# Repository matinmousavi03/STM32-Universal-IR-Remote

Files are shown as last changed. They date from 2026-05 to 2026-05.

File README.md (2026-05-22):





# STM32 Universal IR Recorder & Replayer

An STM32-based embedded system capable of **capturing, storing, and replaying** raw infrared remote control signals with protocol‑independent timing analysis. Unlike protocol‑specific decoders, this project stores raw timing, allowing support for virtually any consumer IR protocol (NEC, RC‑5, Sony SIRC, AC units, etc.).

> **Note:** Schematic, PCB layout, and detailed Persian documentation will be added later in the `hardware/` and `docs/` folders.

<!-- Images coming soon  
![PCB](Images/pcb.jpg)  
*Custom PCB design*  

![Prototype](Images/board.jpg)  
*Hardware prototype on Blue Pill + keypad*  

![IR Waveform](Images/waveform.png)  
*Example captured NEC signal (38 kHz carrier)*  
-->

## Features

- **Protocol‑agnostic** – Works with any consumer IR remote (NEC, RC‑5, Sony SIRC, AC units, etc.)  
  Carrier frequency range 30–56 kHz, raw timing stored with µs precision.
- **Store up to 10 channels** in internal Flash (2 KB per channel, persistent across resets).
- **Replay** stored signals with accurate carrier frequency and timing (PWM + DWT delays).
- **User interface** – 4×4 matrix keypad + status LED.
- **Power management** – Auto standby after 30 seconds idle, wake on keypress.
- **Debug friendly** – UART1 (115200 baud) for real‑time logging.

## Software Architecture

The firmware is built around a **central event‑driven state machine**:

IR_IDLE → IR_RECEIVING → IR_READY → (save/cancel/transmit/delete) → IR_IDLE
(IR_SELECTING for channel choice)

**Timer usage:**

| Timer | Role |
|---|---|
| TIM2  | Input capture of IR edge timing (1 MHz) |
| TIM3  | PWM carrier generation for transmission |
| TIM4  | End‑of‑frame detection (250 ms silence) |
| TIM1  | User decision timeout (5 s) and idle standby |

**Key modules in code:**

- `ProcessDiffBuffer()` – Converts raw `diff` array to `IR_RawData` segments.
- `SaveToFlash()`, `LoadFromFlash()` – Persistent storage in custom Flash sections.
- `IR_Transmit()` – Replays signal using `delay_us()` (DWT cycle counter).
- `ScanKeyboard()` – Polls 4×4 matrix with IRQ disable to avoid false triggers.

## Flash Memory Layout

Custom linker script reserves dedicated Flash pages for persistent data:

| Section | Size  | Purpose |
|---|---|---|
| `.occupied` | 1 KB  | Byte map of channel occupancy (0 = empty, 1 = used) |
| `.user_data`  | 20 KB | Raw IR channel data (10 channels × 2 KB) |

*Both sections are `NOLOAD` to avoid initialisation – they are erased (0xFF) after programming. The firmware detects this and initialises to empty.*

## Hardware Connections

| Component | Pin(s) | Note |
|---|---|---|
| IR receiver input  | **PA15 (TIM2 CH1)** | Falling edge, pull‑up, **partial remap** |
| Wake‑up pin | **PA0 (WKUP)** | Pull‑down, used to exit STANDBY |
| IR transmitter out | PA6 (TIM3 CH1) | PWM, driven by BC107 transistor |
| Keypad rows | PB6, PB7, PB8, PB9 | Outputs, driven LOW during scan |
| Keypad columns | PB3, PB4, PB5, **PB15** | Inputs with pull‑up, EXTI |
| Status LED | PC13 | Active LOW |
| Debug UART | PA9 (TX), PA10 (RX) | 115200 baud |

## Schematic

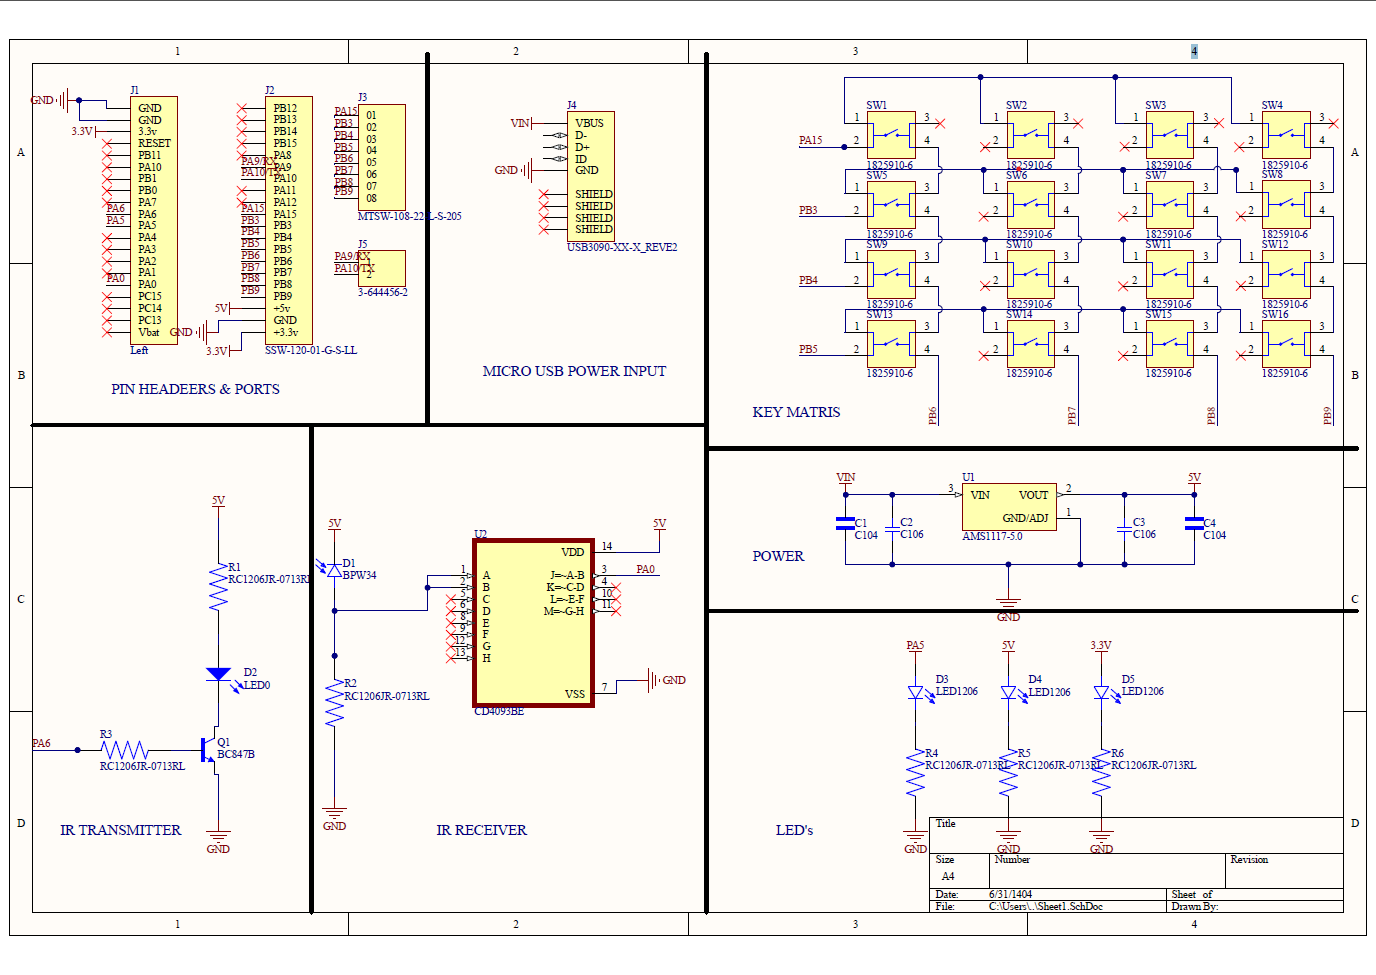
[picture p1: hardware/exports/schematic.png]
Schematic


*Complete schematic of IR receiver, transmitter, keypad, and STM32 connections*

## Hardware Prototype

**Top layer:**  
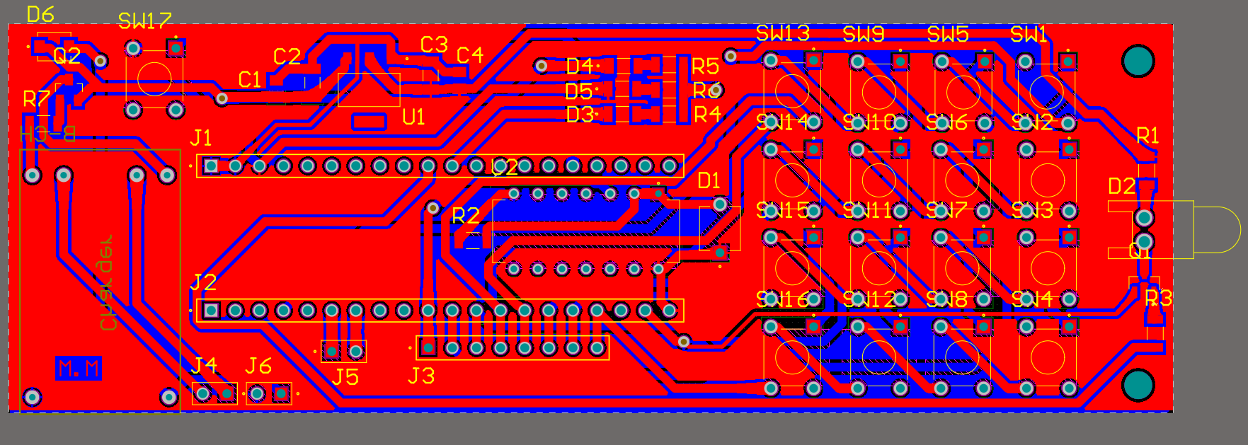
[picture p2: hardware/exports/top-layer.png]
Top layer


<br>

**Bottom layer:**  
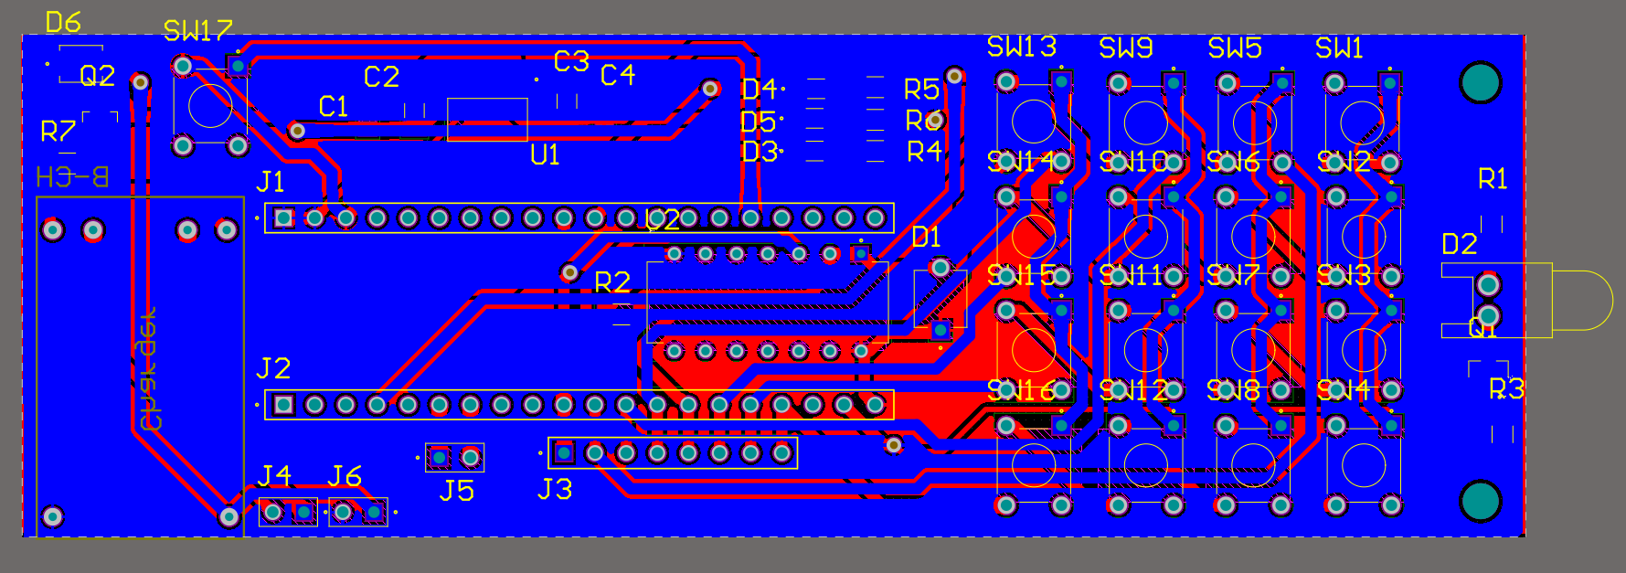
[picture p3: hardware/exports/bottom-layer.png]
Bottom layer


<br>

**3D PCB view:**  
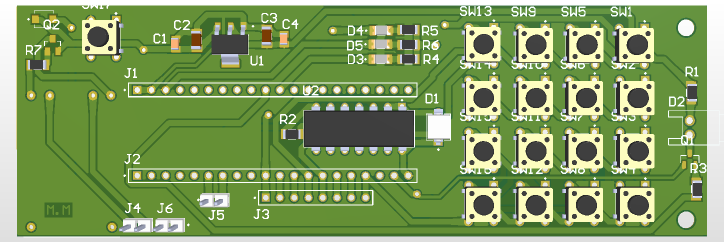
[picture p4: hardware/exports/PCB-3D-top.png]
3D PCB view


## PCB Errata & Design Tips

The following hardware issues were identified in the current PCB revision. Workarounds and fixes for future revisions are provided below.

### 1. IR LED Driver Transistor (Q1) – Footprint Swap
- **Issue:** Base and emitter pins were swapped during routing. The base was connected to GND and the emitter to the PWM signal (TIM3_CH1), making the transistor inoperative.
- **Workaround:** Physically rotate the transistor 180° before soldering (reverse orientation). This corrects the pinout.
- **Fix for next revision:** Correct the footprint so that base connects to the MCU output and emitter goes to GND.

### 2. UART Test Points (J5) & Keypad Connector (J3) Placement
- **Issue:** 
  - **J5 (UART – PA9, PA10):** Positioned too high on the board, difficult to access when mounted in an enclosure.
  - **J3 (Keypad connector):** Unnecessary and placed poorly.
- **Workaround:** 
  - For J5: Use right‑angle (90°) pin headers or manually extend cables.
  - For J3: Do not populate; directly solder keypad wires to the PCB or remove the connector footprint in the next revision.
- **Fix for next revision:** 
  - Move J5 lower on the board or use right‑angle headers.
  - **Remove J3 entirely** – the keypad can be connected via separate wires or a different connector.

### 3. Polygon Pour Clearance
- **Issue:** Large copper pours with insufficient clearance to pads and traces make hand soldering difficult. Heat dissipates quickly, requiring higher soldering temperatures and increasing the risk of bridging.
- **Recommendation:** Increase clearance to at least 0.3 mm (12 mil) or use thermal relief spokes (thermals) on pads connected to pours.
- **Fix for next revision:** Adjust polygon clearance settings and verify thermal reliefs in the PCB layout.

### Hardware Notes

- **TIM2 input capture is remapped to PA15** (`__HAL_AFIO_REMAP_TIM2_PARTIAL_1()`) because PA0 is reserved for the STANDBY wake‑up pin (WKUP). The IR receiver is physically connected to PA15.
- PA0 is configured as a pull‑down input and used only for waking up from STANDBY (EXTI line 0).
- The keypad uses PB15 as its fourth column – **no conflict** with the IR input. All column pins (PB3, PB4, PB5, PB15) have internal pull‑ups and trigger EXTI interrupts for scanning.
- 

## Building the Project

1. Open STM32CubeIDE.
2. **Import the existing project** from the repository root (File → Import → Existing Projects).
3. If you prefer to start fresh, create a new project for STM32F103C8T6 and then replace the generated files:
   - Copy `main.c`, `stm32f1xx_it.c`, `stm32f1xx_hal_msp.c` into `Core/Src/`
   - Copy `stm32f1xx_hal_conf.h` into `Core/Inc/`
   - **Replace the linker script** with `STM32F103C8TX_FLASH.ld` (provided in the root).
4. Compile and flash via ST‑LINK.

> **Important:** The custom linker script defines the two Flash sections (`.user_data` and `.occupied`). Without it, the channel storage will overlap with code and cause hard faults.

## Usage Guide

### 1. Capture a Signal
- Point an existing remote at the IR receiver.
- After capture, the LED lights solid.
- Within 5 seconds:
  - Press `A` to save to the **first free channel**.
  - Or enter a **channel number** (1‑10) then `A` to overwrite/choose a specific channel.
  - Press `B` to discard the signal.

### 2. Transmit a Saved Signal
- Enter a channel number (1‑10), press `#`, then press `C`.

### 3. Delete a Channel
- Enter channel number, press `#`, then press `D`.

### 4. Standby Mode
- After 30 seconds of inactivity, the system enters **STANDBY** (low power). Press any key to wake up.

## Known Issues & Workarounds

- **Occupied page initialisation** – Because `.occupied` is `NOLOAD`, the first read returns `0xFF`. `LoadOccupiedFromFlash()` detects this and resets the map to all empty. If you need a pre‑populated map, remove `NOLOAD` from the linker script and provide initial data.
- **Debouncing** – Only simple software debounce (40 ms in EXTI callback). Very fast double‑presses may be missed, but fine for typical user input.
- **Flash write during capture** – Erasing/programming disables TIM2 and TIM4 interrupts for a few milliseconds. In noisy environments, a capture edge could be lost. A future improvement would be double‑buffering or a background Flash task.
- **EXTI interrupt priority** – Must be **lower than TIM2 capture priority** to avoid race conditions. In this project, EXTI priority is set to 2, TIM2 priority to 1 (configurable via `HAL_NVIC_SetPriority`).

## References

- [STM32F103C8T6 Datasheet](https://www.st.com/resource/en/datasheet/stm32f103c8.pdf) – STMicroelectronics
- [NEC Infrared Transmission Protocol](https://www.renesas.com/us/en/document/apn/nec-infrared-transmission-protocol) – Renesas
- [CD4093B Datasheet (Quad NAND Schmitt Trigger)](https://www.ti.com/lit/ds/symlink/cd4093b.pdf) – Texas Instruments
- [BPW34 Photodiode Datasheet](https://www.vishay.com/docs/81521/bpw34.pdf) – Vishay
- [STM32 HAL Driver User Manual](https://www.st.com/resource/en/user_manual/dm00105879-description-of-stm32f1-hal-and-lowlayer-drivers-stmicroelectronics.pdf)

## License

MIT License – see [LICENSE](LICENSE) file for details.

---

## Suggested GitHub Topics

`stm32` `stm32f103` `embedded` `embedded-c` `stm32-hal` `infrared` `ir-remote` `electronics` `microcontroller` `ir-decoder` `universal-remote`

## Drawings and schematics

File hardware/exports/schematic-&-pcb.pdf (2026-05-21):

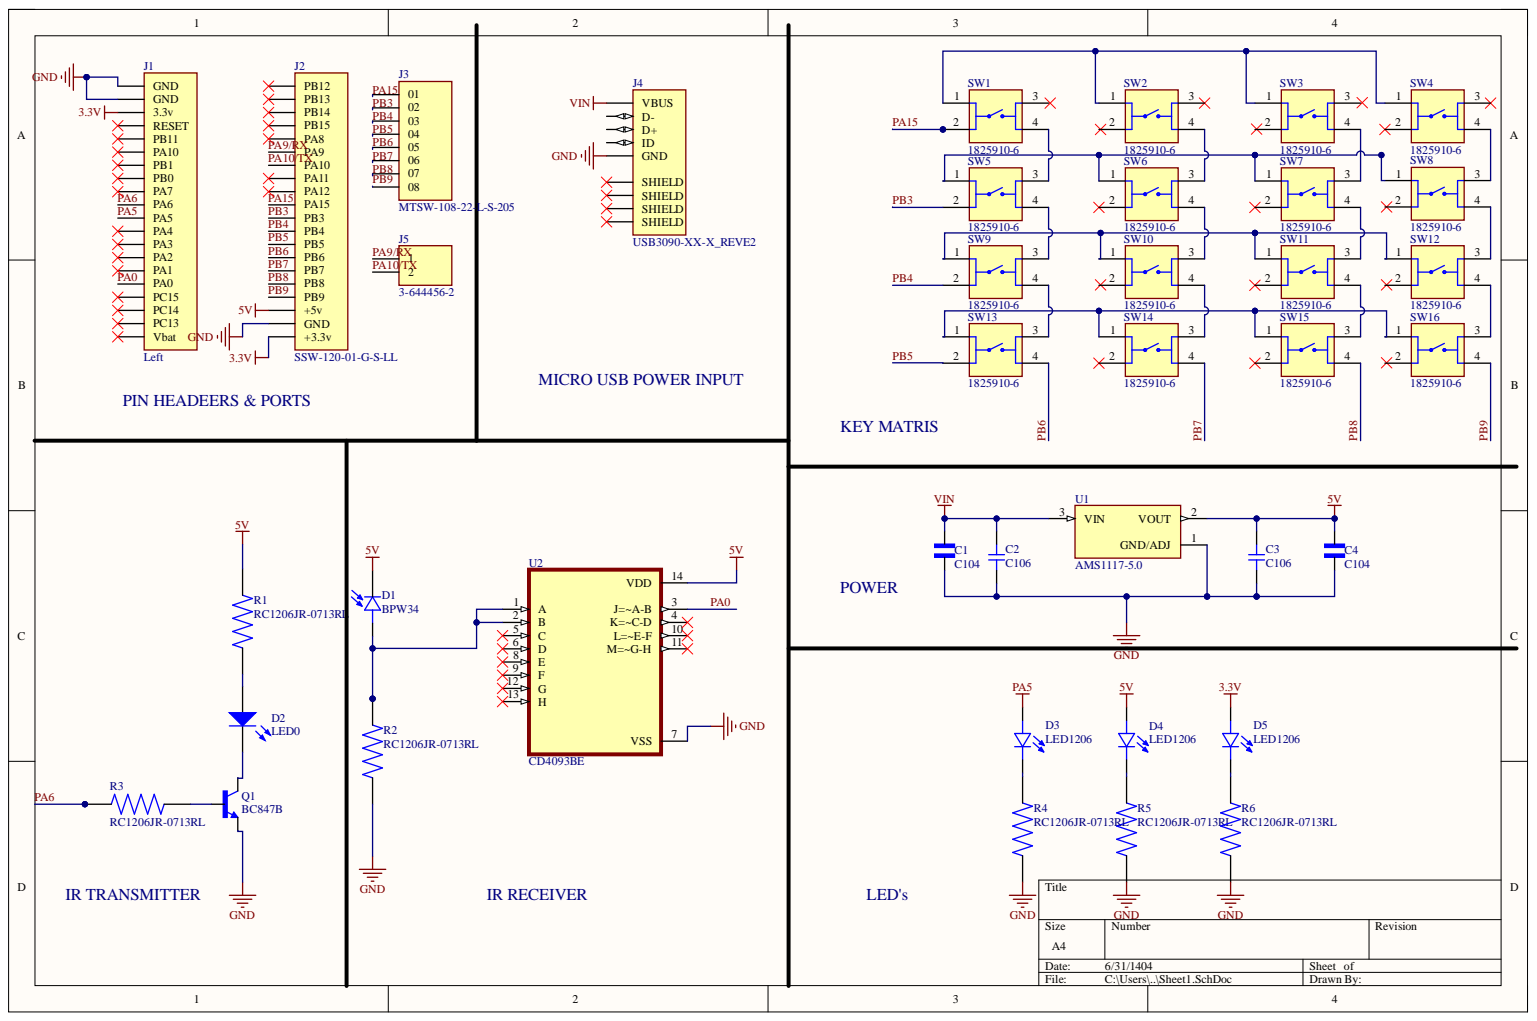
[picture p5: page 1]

5 | 1 0

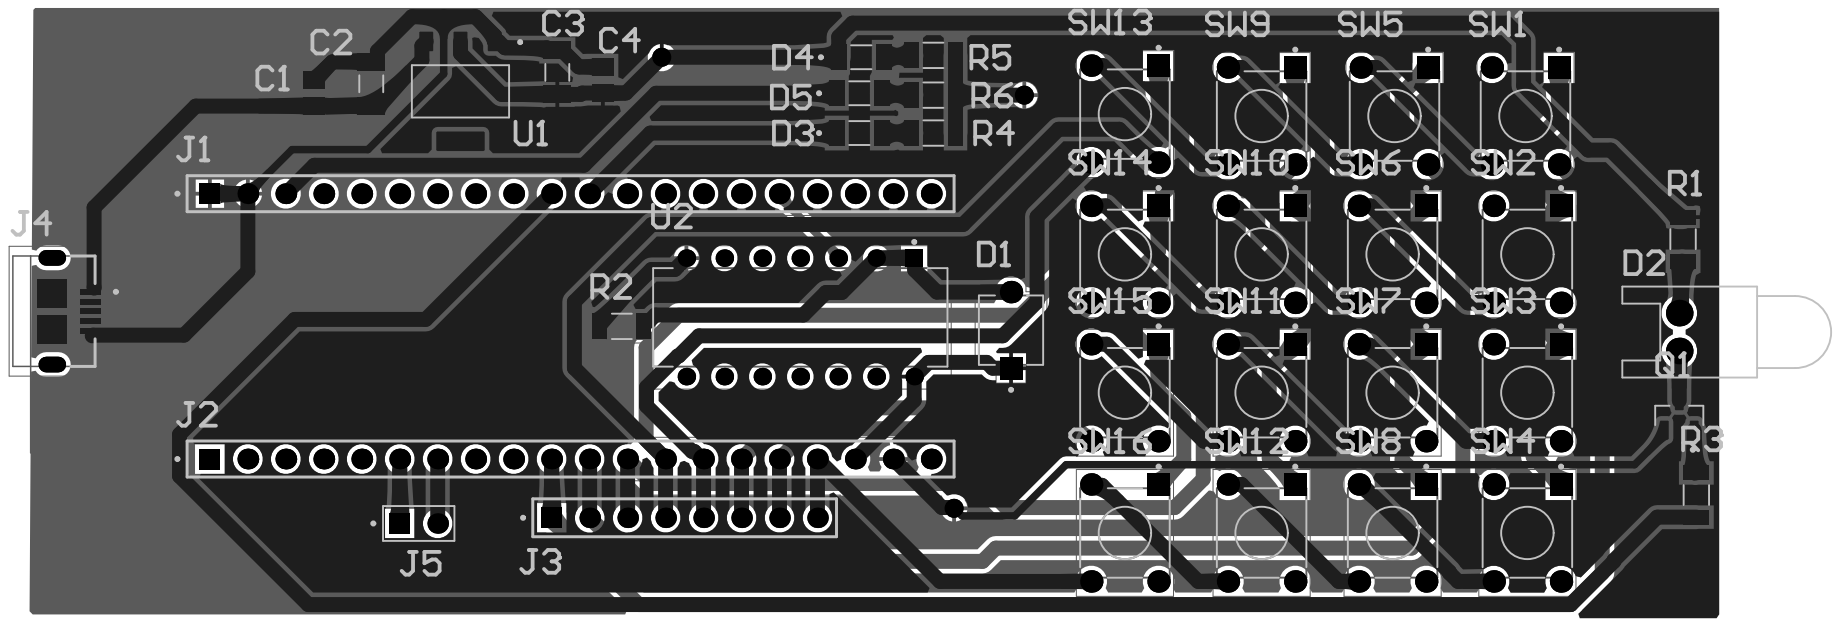
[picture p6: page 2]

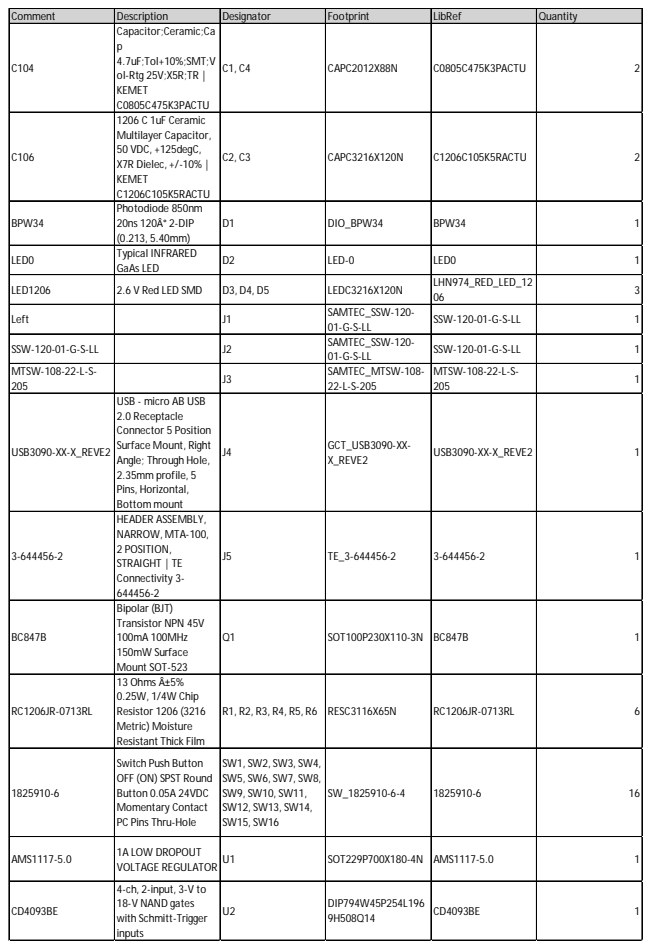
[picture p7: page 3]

Comment | Description | Designator | Footprint | LibRef | Quantity
C104 | Capacitor;Ceramic;Ca p 4.7uF;Tol+10%;SMT;V ol-Rtg 25V;X5R;TR | KEMET C0805C475K3PACTU | C1, C4 | CAPC2012X88N | C0805C475K3PACTU | 2

C106 | 1206 C 1uF Ceramic Multilayer Capacitor, 50 VDC, +125degC, X7R Dielec, +/-10% | KEMET C1206C105K5RACTU | C2, C3 | CAPC3216X120N | C1206C105K5RACTU | 2

BPW34 | Photodiode 850nm 20ns 120Â° 2-DIP (0.213, 5.40mm) | D1 | DIO_BPW34 | BPW34 | 1

LED0 | Typical INFRARED GaAs LED | D2 | LED-0 | LED0 | 1

LED1206 | 2.6 V Red LED SMD | D3, D4, D5 | LEDC3216X120N | LHN974_RED_LED_12 06 | 3

Left | | J1 | SAMTEC_SSW-120-01-G-S-LL | SSW-120-01-G-S-LL | 1

SSW-120-01-G-S-LL | | J2 | SAMTEC_SSW-120-01-G-S-LL | SSW-120-01-G-S-LL | 1

MTSW-108-22-L-S-205 | | J3 | SAMTEC_MTSW-108-22-L-S-205 | MTSW-108-22-L-S-205 | 1

USB3090-XX-X_REVE2 | USB - micro AB USB 2.0 Receptacle Connector 5 Position Surface Mount, Right Angle; Through Hole, 2.35mm profile, 5 Pins, Horizontal, Bottom mount | J4 | GCT_USB3090-XX-X_REVE2 | USB3090-XX-X_REVE2 | 1

3-644456-2 | HEADER ASSEMBLY, NARROW, MTA-100, 2 POSITION, STRAIGHT | TE Connectivity 3-644456-2 | J5 | TE_3-644456-2 | 3-644456-2 | 1

BC847B | Bipolar (BJT) Transistor NPN 45V 100mA 100MHz 150mW Surface Mount SOT-523 | Q1 | SOT100P230X110-3N | BC847B | 1

RC1206JR-0713RL | 13 Ohms Â±5% 0.25W, 1/4W Chip Resistor 1206 (3216 Metric) Moisture Resistant Thick Film | R1, R2, R3, R4, R5, R6 | RESC3116X65N | RC1206JR-0713RL | 6

1825910-6 | Switch Push Button OFF (ON) SPST Round Button 0.05A 24VDC Momentary Contact PC Pins Thru-Hole | SW1, SW2, SW3, SW4, SW5, SW6, SW7, SW8, SW9, SW10, SW11, SW12, SW13, SW14, SW15, SW16 | SW_1825910-6-4 | 1825910-6 | 16

AMS1117-5.0 | 1A LOW DROPOUT VOLTAGE REGULATOR | U1 | SOT229P700X180-4N | AMS1117-5.0 | 1

CD4093BE | 4-ch, 2-input, 3-V to 18-V NAND gates with Schmitt-Trigger inputs | U2 | DIP794W45P254L196 9H508Q14 | CD4093BE | 1

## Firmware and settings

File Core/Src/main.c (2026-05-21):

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
/* Includes ------------------------------------------------------------------*/
#include "main.h"

/* USER CODE BEGIN Includes */
#include <string.h>
#include <stdio.h>

#include "stm32f1xx_hal.h"
#include "stm32f1xx_hal_rcc.h"

#include <stdlib.h>  // for atoi


/* Reserve Flash space for channel storage (10 channels * 2KB each) */
__attribute__((section(".user_data"))) const uint8_t flash_channels[10 * 2048];
/* Reserve one Flash page (1KB) for occupied channel map */
__attribute__((section(".occupied"))) const uint8_t occupied_page[1024];

/* USER CODE END Includes */

/* USER CODE BEGIN PD */

/* IR signal processing thresholds */
#define BURST_GAP_US    70        /* Max duration to consider as part of a burst (carrier) */
#define MAX_SEGMENTS    256       /* Max number of burst/idle segments per signal */
#define MAX_DIFFS       3000      /* Reduced from 4096 to save RAM (8KB) */
#define TIMER_FREQ_HZ   1000000   /* TIM2 runs at 1 MHz → 1 µs per tick */
#define END_GAP_US      500000    /* 500 ms silence to force end of capture (fallback) */

/* Signal validation thresholds */
#define MIN_CARRIER_COUNT 5          /* Minimum pulses to calculate carrier frequency */
#define MIN_TOTAL_DURATION_US 50000  /* Minimum total signal duration (50 ms) */
#define MAX_TOTAL_DURATION_US 200000 /* Maximum total signal duration (200 ms) */
#define MIN_BURST_DURATION_US 100    /* Minimum burst length to reject noise */
#define MIN_IDLE_DURATION_US  50     /* Minimum idle length to reject short gaps */
#define CARRIER_FREQ_MIN_HZ   30000  /* Min carrier frequency (30 kHz) */
#define CARRIER_FREQ_MAX_HZ   50000  /* Max carrier frequency (50 kHz) */
#define MIN_DIFFS_FOR_PROCESS 10     /* Ignore signals with fewer diffs (noise) */

/* Flash memory layout */
#define FLASH_END_ADDRESS           0x08010000  /* End of 64KB Flash (base + 64KB) */
#define MY_FLASH_PAGE_SIZE          1024U       /* Page size (renamed to avoid conflict(redefining FLASH_PAGE_SIZE error)) */
#define FLASH_OCCUPIED_START ((uint32_t)occupied_page)
#define FLASH_CHANNELS_START ((uint32_t)flash_channels)
#define CHANNEL_SIZE_IN_FLASH       (MY_FLASH_PAGE_SIZE * PAGES_PER_CHANNEL) // حالا با MY_ استفاده می‌شه

/* IR channel configuration */
#define MAX_CHANNELS    10
#define PAGES_PER_CHANNEL    2   /* 2 pages = 2KB per channel */

#define IDLE_THRESHOLD 6  /* 6 * 5s = 30s idle timeout */

/* USER CODE END PD */

TIM_HandleTypeDef htim1;
TIM_HandleTypeDef htim2;
TIM_HandleTypeDef htim3;
TIM_HandleTypeDef htim4;

UART_HandleTypeDef huart1;

/* USER CODE BEGIN PV */

/* EXTI flag for keypad interrupt */
volatile uint8_t exti_flag = 0;

/* Raw diff buffer (timing between edges) */
volatile uint32_t diffBuffer[MAX_DIFFS];
volatile uint32_t diffIndex = 0;

/* Capture state flags */
volatile uint8_t captureActive = 1;       /* Set to 0 to stop capture */
volatile uint8_t signalDetected = 0;      /* First valid edge detected */

/* Structure to hold processed IR signal data */
typedef struct {
    uint32_t carrierFreq;
    uint16_t segmentCount;
    uint8_t  type[MAX_SEGMENTS];      /* 0 = Idle, 1 = Burst */
    uint32_t duration[MAX_SEGMENTS];  /* microseconds */
} IR_RawData;

/* Current captured signal (volatile because used in ISR) */
volatile IR_RawData irData;

volatile uint32_t lastCapture = 0;
volatile uint8_t signalReady = 0;     /* Set when capture finished or overflow */
volatile uint8_t overflowError = 0;   /* Diff buffer overflow flag */

//phase 3
/* Temporary buffer for Flash read/write (one channel) */
IR_RawData tempChannelData;

/* State machine states */
typedef enum {
    IR_IDLE,         /* Waiting for signal or user input */
    IR_RECEIVING,    /* Capture in progress */
    IR_READY,        /* Signal ready, waiting for save/cancel */
    IR_TRANSMITTING, /* Replaying stored signal */
	IR_SELECTING     /* User selected channel, waiting for C (send) or D (delete) */
} IR_State;

volatile IR_State currentState = IR_IDLE;

/* Channel occupancy map (0 = free, 1 = occupied) */
uint8_t channelOccupied[MAX_CHANNELS] = {0};

/* Keyboard input buffer (max 2 digits + null terminator) */
uint8_t selectedChannel = 0;
uint8_t keyboardBuffer[3] = {0};
uint8_t keyboardIndex = 0;

/* User timeout duration (not used dynamically yet, kept for future) */
//uint32_t timeoutDuration = 0;

/* Button flags for polling in main loop (not used in current implementation) */
//uint8_t savePressed = 0, cancelPressed = 0, sendPressed = 0, deletePressed = 0;

/* Word-aligned buffer for Flash programming (BSS) */
static uint32_t saveBuf[(sizeof(IR_RawData) + 3) / 4];

//phase 4
/* Idle timeout handling for standby mode */
volatile uint32_t lastActivityTime = 0;
const uint32_t IDLE_TIMEOUT_MS = 30000;

/* USER CODE END PV */

void SystemClock_Config(void);
static void MX_GPIO_Init(void);
static void MX_TIM2_Init(void);
static void MX_USART1_UART_Init(void);
static void MX_TIM4_Init(void);
static void MX_TIM3_Init(void);
static void MX_TIM1_Init(void);
/* USER CODE BEGIN PFP */

//phase 3
/* Channel management */
static uint8_t FindNextFreeChannel(void);
static void SaveChannel(uint8_t ch);
static void DeleteChannel(uint8_t ch);

/* Flash operations */
HAL_StatusTypeDef SaveToFlash(uint8_t channelIndex, IR_RawData* data);
void LoadFromFlash(uint8_t channelIndex, IR_RawData* destination);
static void LoadOccupiedFromFlash(void);  /* Load channel occupancy from Flash at startup */
static HAL_StatusTypeDef SaveOccupiedToFlash(void);

/* User interface */
static uint8_t ScanKeyboard(void);  /* Scan 4x4 keypad, return ASCII key or 0 */
static void ProcessKeyboardInput(uint8_t key);
static void LED_Pattern(uint8_t type);  /* type: 1=save, 2=cancel, 3=send, 4=delete, 5=error */

/* Debug helpers */
static void DumpOccupiedFlashRaw(void);

/* User timeout management (TIM1) */
static inline void StartUserTimeout(void);
static inline void StopUserTimeout(void);

/* USER CODE END PFP */

/* USER CODE BEGIN 0 */

/**
 * @brief Initializes and starts IR capture mode.
 *        Resets buffers, flags, and starts TIM2 input capture interrupt.
 */
void IR_CaptureStart(void)
{
    memset((void*)diffBuffer, 0, sizeof(diffBuffer));
    diffIndex = 0;
    signalReady = 0;
    overflowError = 0;
    lastCapture = 0;
    captureActive = 1;
    signalDetected = 0;

    HAL_TIM_IC_Start_IT(&htim2, TIM_CHANNEL_1);
    currentState = IR_IDLE;
	printf("Entered receiving state.\r\n");

}

/**
 * @brief TIM2 input capture interrupt callback.
 *        Measures time between falling edges, stores diffs in buffer,
 *        and starts TIM4 timeout on first valid edge.
 */
void HAL_TIM_IC_CaptureCallback(TIM_HandleTypeDef *htim)
{
    if (htim->Instance != TIM2 || !captureActive) return;

    uint32_t now = HAL_TIM_ReadCapturedValue(htim, TIM_CHANNEL_1);
    uint32_t diff = (now >= lastCapture) ? (now - lastCapture) : (0xFFFF - lastCapture + now + 1);

    /* Skip first capture (no valid diff) */
    if (lastCapture == 0) {
            lastCapture = now;
            return;
    }

    if (diffIndex < MAX_DIFFS) {
        diffBuffer[diffIndex++] = diff;
    } else {
    	/* Buffer overflow: stop capture and signal ready for processing */
        overflowError = 1;
        captureActive = 0;
        HAL_TIM_IC_Stop_IT(&htim2, TIM_CHANNEL_1);
        HAL_TIM_Base_Stop_IT(&htim4);
        signalReady = 1;
    }

    lastCapture = now;

    /* Start TIM4 timeout only on the first valid edge */
    if (!signalDetected) {
        signalDetected = 1;
        __HAL_TIM_SET_COUNTER(&htim4, 0);
        HAL_TIM_Base_Start_IT(&htim4);
        currentState = IR_RECEIVING;

    }
}

/**
 * @brief TIM period elapsed callback (used by TIM4 and TIM1).
 *        TIM4: end-of-frame detection, stops capture.
 *        TIM1: user decision timeout (5s), discards signal or selection.
 */
__attribute__((used)) void HAL_TIM_PeriodElapsedCallback(TIM_HandleTypeDef *htim) {
    if (htim->Instance == TIM4) {
    	/* End of capture timeout (no signal edge for 250ms) */
        if (captureActive) {
            captureActive = 0;
            HAL_TIM_IC_Stop_IT(&htim2, TIM_CHANNEL_1);
            HAL_TIM_Base_Stop_IT(&htim4);
            signalReady = 1;  /* Signal ready for processing */
        }
        return;
    }

    if (htim->Instance == TIM1) {

    	/* 5-second user timeout window (ready or channel selection) */
    	StopUserTimeout();

        if (currentState == IR_READY) {
        	lastActivityTime = HAL_GetTick();
        	printf("Timeout in ready state: Signal discarded.\r\n");
            //LED_Pattern(2);
            HAL_GPIO_WritePin(GPIOC, GPIO_PIN_13, GPIO_PIN_SET); /* Turn LED off */
            currentState = IR_IDLE;
            selectedChannel = 0;
            keyboardIndex = 0;
            memset(keyboardBuffer, 0, sizeof(keyboardBuffer));
            //printf("Timeout in ready state: Signal discarded.\r\n");
            IR_CaptureStart(); /* Restart capture */
        }
        else if (currentState == IR_SELECTING && selectedChannel > 0) {
        	lastActivityTime = HAL_GetTick();
            printf("Timeout in channel selection: Channel %d discarded.\r\n", selectedChannel);
            selectedChannel = 0;
            HAL_GPIO_WritePin(GPIOC, GPIO_PIN_13, GPIO_PIN_SET); /* Turn LED off */
            currentState = IR_IDLE;
            IR_CaptureStart();
        }

        return;
    }
}


/**
 * @brief Retarget printf to UART1.
 * @param file unused
 * @param ptr data buffer
 * @param len length
 * @return number of bytes written
 */
int _write(int file, char *ptr, int len)
{
    HAL_UART_Transmit(&huart1, (uint8_t*)ptr, len, HAL_MAX_DELAY);
    return len;
}

/**
 * @brief Show visual feedback on LED (PC13, active low).
 * @param type 1=Save, 2=Cancel, 3=Send, 4=Delete, 5=Error
 */
void LED_Pattern(uint8_t type) {
    switch (type) {
        case 1:  /* Save: 3 quick blinks */
            for (int i = 0; i < 3; i++) {
                HAL_GPIO_WritePin(GPIOC, GPIO_PIN_13, GPIO_PIN_RESET);
                HAL_Delay(150);
                HAL_GPIO_WritePin(GPIOC, GPIO_PIN_13, GPIO_PIN_SET);
                HAL_Delay(150);
            }
            break;
        case 2:  /* Save: 3 quick blinks */
            HAL_GPIO_WritePin(GPIOC, GPIO_PIN_13, GPIO_PIN_RESET);
            HAL_Delay(500);
            HAL_GPIO_WritePin(GPIOC, GPIO_PIN_13, GPIO_PIN_SET);
            HAL_Delay(200);
            break;
        case 3:  /* Send: 2 medium blinks */
            for (int i = 0; i < 2; i++) {
                HAL_GPIO_WritePin(GPIOC, GPIO_PIN_13, GPIO_PIN_RESET);
                HAL_Delay(300);
                HAL_GPIO_WritePin(GPIOC, GPIO_PIN_13, GPIO_PIN_SET);
                HAL_Delay(300);
            }
            break;
        case 4:  /* Delete: 4 fast blinks */
            for (int i = 0; i < 4; i++) {
                HAL_GPIO_WritePin(GPIOC, GPIO_PIN_13, GPIO_PIN_RESET);
                HAL_Delay(100);
                HAL_GPIO_WritePin(GPIOC, GPIO_PIN_13, GPIO_PIN_SET);
                HAL_Delay(100);
            }
            break;
        case 5:  /* Error: 5 very fast blinks */
			for (int i = 0; i < 5; i++) {
				HAL_GPIO_WritePin(GPIOC, GPIO_PIN_13, GPIO_PIN_RESET);
				HAL_Delay(50);
				HAL_GPIO_WritePin(GPIOC, GPIO_PIN_13, GPIO_PIN_SET);
				HAL_Delay(50);
			}
			break;
        default:
            break;
    }
}

/**
 * @brief Dynamically set TIM3 PWM frequency for IR carrier.
 * @param carrierHz Desired carrier frequency (30-56 kHz). Out-of-range defaults to 38 kHz.
 */
void TIM3_SetCarrierFreq(uint32_t carrierHz)
{
    if (carrierHz < 30000 || carrierHz > 50000) {
        carrierHz = 38000; /* Default to 38 kHz */
    }

    /* Calculate timer clock (APB1) */
    uint32_t pclk1 = HAL_RCC_GetPCLK1Freq();
    uint32_t hclk = HAL_RCC_GetHCLKFreq();  // HCLK usually = SYSCLK
    uint32_t tim_clk = (pclk1 == hclk) ? pclk1 : 2 * pclk1;  /* If APB1 prescaler >1, timer clock = 2*PCLK1 */

    /* Adjust prescaler to avoid 16-bit overflow */
    uint32_t prescaler = 0;
    uint32_t period = tim_clk / carrierHz;
    while (period > 65535) {
        prescaler++;
        period = (tim_clk / (prescaler + 1)) / carrierHz;
    }
    if (period == 0) period = 1;  // prevents division by zero
    period -= 1; /* Final ARR value */

    /* Apply settings without reinitializing the timer */
    __HAL_TIM_SET_PRESCALER(&htim3, prescaler);
    __HAL_TIM_SET_AUTORELOAD(&htim3, period);

    /* Duty cycle ≈ 33% (can be changed to 50% by using period/2) */
    __HAL_TIM_SET_COMPARE(&htim3, TIM_CHANNEL_1, period / 2);
}

/**
 * @brief Enable PWM output on TIM3 channel 1.
 */
static inline void PWM_On(void) {
    HAL_TIM_PWM_Start(&htim3, TIM_CHANNEL_1);
}

/**
 * @brief Disable PWM output on TIM3 channel 1.
 */
static inline void PWM_Off(void) {
    HAL_TIM_PWM_Stop(&htim3, TIM_CHANNEL_1);
}

/**
 * @brief Microsecond delay using DWT cycle counter.
 * @param us Delay in microseconds
 */
static void delay_us(uint32_t us)
{
    uint32_t start = DWT->CYCCNT;
    uint32_t cycles = (HAL_RCC_GetHCLKFreq() / 1000000) * us;
    while ((DWT->CYCCNT - start) < cycles);
}

/**
 * @brief Replay a stored IR signal.
 * @param data Pointer to IR_RawData structure (carrier freq, segments, durations)
 */
void IR_Transmit(volatile IR_RawData *data)
{
    if (data->segmentCount == 0) {
        printf("Error: No segments to transmit.\r\n");
        return;
    }
    currentState = IR_TRANSMITTING;
	printf("Transmitting channel %d...\r\n", selectedChannel);
	LED_Pattern(3);   /* Send pattern */

    TIM3_SetCarrierFreq(data->carrierFreq); /* Dynamic frequency setting based on captured carrier */

    for (uint16_t i = 0; i < data->segmentCount; i++) {
        if (data->type[i] == 1) {
            PWM_On();
        } else {
            PWM_Off();
        }
        delay_us(data->duration[i]);
    }
    PWM_Off(); /* Final off */
	printf("Transmit complete.\r\n");
	currentState = IR_IDLE;
	selectedChannel = 0;
	IR_CaptureStart();  /* Back to idle, ready for next capture */
}
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
int main(void)
{

  /* MCU Configuration--------------------------------------------------------*/

  /* Reset of all peripherals, Initializes the Flash interface and the Systick. */
  HAL_Init();

  /* Configure the system clock */
  SystemClock_Config();

  /* Initialize all configured peripherals */
  MX_GPIO_Init();
  MX_TIM2_Init();
  MX_USART1_UART_Init();
  MX_TIM4_Init();
  MX_TIM3_Init();
  MX_TIM1_Init();
  /* USER CODE BEGIN 2 */

  /* Configure PA0 as input with pull-down for standby wake-up (WKUP) */
  GPIO_InitTypeDef GPIO_InitStruct = {0};
  GPIO_InitStruct.Pin = GPIO_PIN_0;  // PA0
  GPIO_InitStruct.Mode = GPIO_MODE_INPUT;
  GPIO_InitStruct.Pull = GPIO_PULLDOWN;  // pull-down
  HAL_GPIO_Init(GPIOA, &GPIO_InitStruct);

  /* Disable wakeup pin initially (used for standby mode) */
  HAL_PWR_DisableWakeUpPin(PWR_WAKEUP_PIN1);


  /* Check if the microcontroller is waking up from STANDBY mode */
  if (__HAL_PWR_GET_FLAG(PWR_FLAG_SB) != RESET) {
      /*
       * STANDBY mode is the deepest sleep mode. When the MCU wakes up,
       * it performs a power-on reset and restarts execution from main().
       * The PWR_FLAG_SB flag indicates that the reset was caused by
       * waking from STANDBY rather than a normal power-up or hardware reset.
       */

      /* Clear the STANDBY flag to avoid re‑detection on next reset */
      __HAL_PWR_CLEAR_FLAG(PWR_FLAG_SB);

      /* Also clear the wake‑up flag (set when a wake‑up event occurred) */
      __HAL_PWR_CLEAR_FLAG(PWR_FLAG_WU);

      /*
       * Disable the wake‑up pin (PA0) to prevent immediate re‑entry into
       * standby after we exit this boot sequence. The pin will be re‑enabled
       * later when the idle timeout triggers standby again.
       */
      HAL_PWR_DisableWakeUpPin(PWR_WAKEUP_PIN1);

      /* Optional debug message to confirm wake‑up source */
      printf("Woke up from STANDBY. Restarting init.\r\n");
  }
	/* Reset idle counter */
    lastActivityTime = HAL_GetTick();

    /* Enable DWT cycle counter for microsecond delays */
	CoreDebug->DEMCR |= CoreDebug_DEMCR_TRCENA_Msk;
	DWT->CYCCNT = 0;
	DWT->CTRL |= DWT_CTRL_CYCCNTENA_Msk;

	LoadOccupiedFromFlash();
	printf("Occupied map: ");
	for (int i=0;i<MAX_CHANNELS;i++){
		printf("%d", channelOccupied[i] ? 1 : 0);
		if (i < MAX_CHANNELS-1) printf(",");
	}
	printf("\r\n");
	DumpOccupiedFlashRaw();

	printf("IR Raw Receiver Started... Flash base: 0x%08lX (%d channels, %d pages each)\r\n",
		   (unsigned long)FLASH_CHANNELS_START, MAX_CHANNELS, PAGES_PER_CHANNEL);
	LED_Pattern(1);   /* Test LED */
	//  printf("IR Raw Receiver Started...\r\n");
	//  BlinkPattern_OK();
	IR_CaptureStart();

	 /* Set PA5 low (active state) – used as a wake-up indicator */
	HAL_GPIO_WritePin(GPIOA, GPIO_PIN_5, GPIO_PIN_RESET);


  /* USER CODE END 2 */

  /* Infinite loop */
  /* USER CODE BEGIN WHILE */
  while (1)
    {
	  // UPDATED: اسکن کیبورد (در هر state)
//		uint8_t key = ScanKeyboard();
//		if (key) {
//			ProcessKeyboardInput(key);
//		}
	  /* Check idle timeout – enter STANDBY after 30 seconds of inactivity */
	  if (currentState == IR_IDLE && (HAL_GetTick() - lastActivityTime >= IDLE_TIMEOUT_MS)) {
		  printf("30s idle timeout. Entering Standby mode...\r\n");

		  /* Set PA5 high to indicate standby state (active low before) */
		  HAL_GPIO_WritePin(GPIOA, GPIO_PIN_5, GPIO_PIN_SET);

		  /* Stop all peripherals to save power */
		  HAL_TIM_Base_Stop_IT(&htim1);
		  HAL_TIM_IC_Stop_IT(&htim2, TIM_CHANNEL_1);
		  HAL_TIM_PWM_Stop(&htim3, TIM_CHANNEL_1);
		  HAL_TIM_Base_Stop_IT(&htim4);

		  /* Enable wake‑up pin and enter STANDBY mode */
		  HAL_PWR_EnableWakeUpPin(PWR_WAKEUP_PIN1);
		  HAL_PWR_EnterSTANDBYMode();
		  /* The MCU resets after waking from STANDBY */
	  }
	  /* Process EXTI flag (keypad interrupt) – consume and optionally debug */
	  if (exti_flag) {
		  exti_flag = 0;                     // consume the flag (one-shot)
		  printf("EXTI event detected! (flag processed)\r\n");
		  /* Additional processing can be added here if needed */
	  }
	  /* Scan keypad and handle user input */
	  uint8_t key = ScanKeyboard();
		if (key) {
			lastActivityTime = HAL_GetTick();  /* Reset idle timer on any key press */
			ProcessKeyboardInput(key);
		}

		/* If a signal capture is complete, process it */
		if (signalReady) {
			/* Valid signal – enter READY state and turn LED on solid */
			signalReady = 0;
			uint8_t result = ProcessDiffBuffer();
			lastActivityTime = HAL_GetTick();  /* User interaction resets idle timer */

			if (result) {
				currentState = IR_READY;
				HAL_GPIO_WritePin(GPIOC, GPIO_PIN_13, GPIO_PIN_RESET);

				/* Print captured signal details for debugging */
				printf("\r\n--- New Valid Signal Captured ---\r\n");
				printf("Carrier Frequency: %lu Hz\r\n", irData.carrierFreq);
				printf("Segment Count: %d\r\n", irData.segmentCount);
				for (int i = 0; i < irData.segmentCount; i++) {
					const char* typeStr = (irData.type[i] == 1) ? "Burst" : "Idle ";
					printf("Segment %02d: [%s] -> %lu us\r\n", i, typeStr, irData.duration[i]);
				}
				printf("--- End of Signal ---\r\n\r\n");

				/* Suggest next free channel or overwrite option */
				uint8_t nextCh = FindNextFreeChannel();
				if (nextCh == 0) {
					printf("All channels full. Enter number then A to overwrite, or B (Cancel).\r\n");
					nextCh = 1;  /* Default to overwrite channel 1 */
				} else {
					printf("Save to channel %d? Press A (Save), or enter number then A, or B (Cancel).\r\n", nextCh);
				}
				/* Start 5-second timeout for user decision */
				StartUserTimeout();
			} else {
				/* Invalid signal – discard and restart capture */
				if (diffIndex >= MIN_DIFFS_FOR_PROCESS) {
					LED_Pattern(2);  // Cancel pattern
					printf("\r\n--- Invalid Signal Discarded. Resetting... ---\r\n");
				}
				IR_CaptureStart();
			}
		}

		/* Small delay to prevent excessive CPU usage while polling */
		HAL_Delay(100);

    /* USER CODE END WHILE */

    /* USER CODE BEGIN 3 */
    }
  /* USER CODE END 3 */
}

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


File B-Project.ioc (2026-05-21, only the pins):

Mcu.UserName=STM32F103C8Tx
PA0-WKUP.Signal=SYS_WKUP
PA10.Signal=USART1_RX
PA13.Signal=SYS_JTMS-SWDIO
PA14.Signal=SYS_JTCK-SWCLK
PA15.Signal=S_TIM2_CH1_ETR
PA5.Signal=GPIO_Output
PA6.Signal=S_TIM3_CH1
PA9.Signal=USART1_TX
PB15.Signal=GPXTI15
PB3.Signal=GPXTI3
PB4.Signal=GPXTI4
PB5.Signal=GPXTI5
PB6.Signal=GPIO_Output
PB7.Signal=GPIO_Output
PB8.Signal=GPIO_Output
PB9.Signal=GPIO_Output
PC13-TAMPER-RTC.Signal=GPIO_Output
PD0-OSC_IN.Signal=RCC_OSC_IN
PD1-OSC_OUT.Signal=RCC_OSC_OUT

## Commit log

2026-05-21 Initial commit: STM32 Universal IR Recorder & Replayer
    [PCB1.PcbDoc, PCB_Project.PrjPcb, Sheet1.SchDoc]
2026-05-22 Update README.md
    adding 3 images of PCB design
2026-05-22 Revise hardware design to include prototype information
    Updated hardware design section to reflect prototype details and improved image references.
2026-05-22 Add schematic section to README
    Added schematic section with image and description.
2026-05-22 Add schematic image
2026-05-22 Document PCB issues and recommended fixes
    Added PCB errata and design tips section to README.
